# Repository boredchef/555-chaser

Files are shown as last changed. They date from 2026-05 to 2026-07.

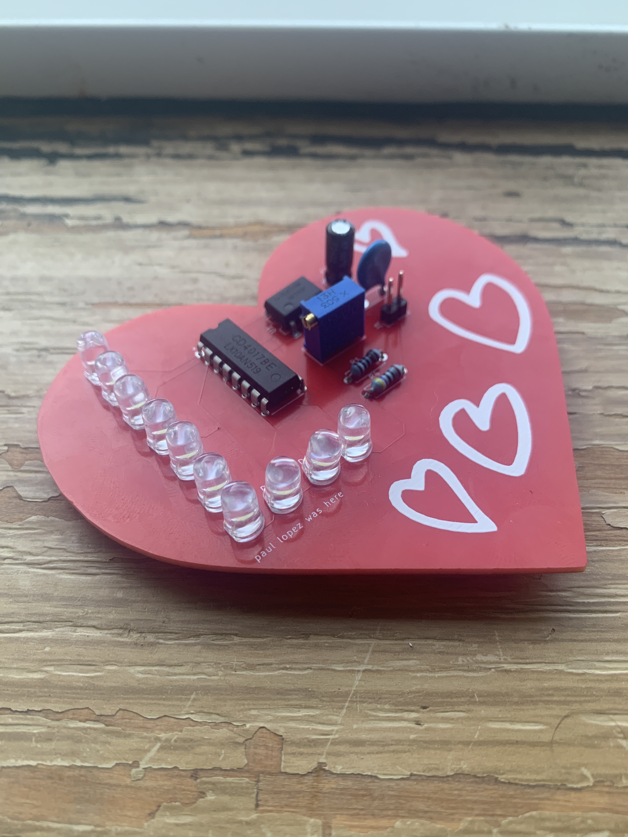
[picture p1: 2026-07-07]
IMG_1859.JPG

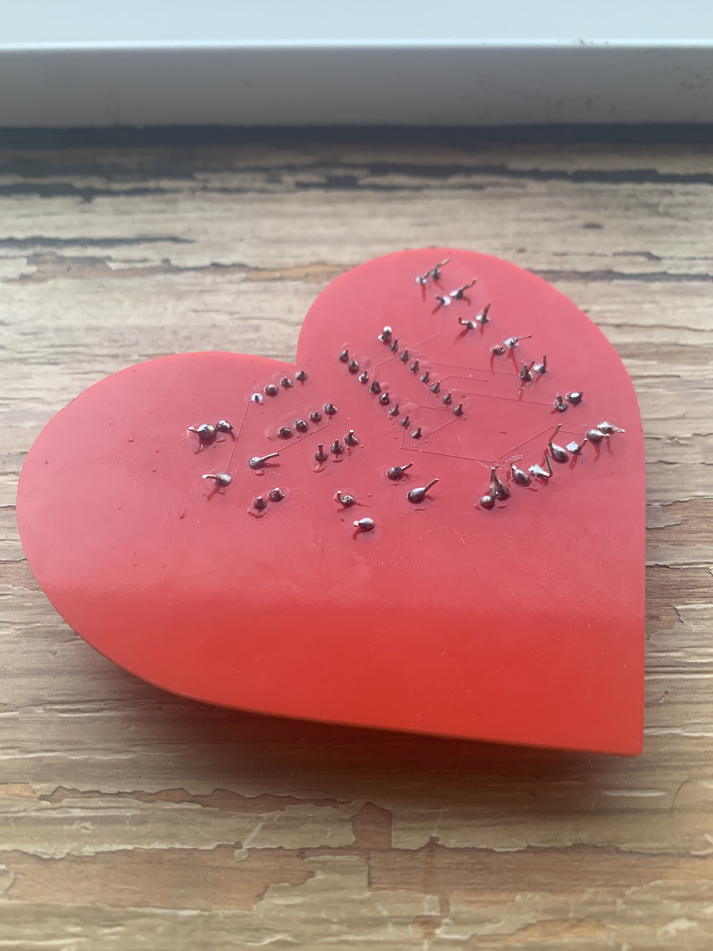
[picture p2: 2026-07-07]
IMG_1860.JPG

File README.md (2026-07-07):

# 555-chaser
I made this heart shaped led chaser PCB from the start project tutorial on Stasis. How it works is that it uses 2 different ICs which is the 555 timer and the 4017 IC. The 555 component basically is the brains to make the leds blink on and off using astable mode which produces an signal that swithces from on and off. Since we are using a lot of LEDs there is not enough pins on the 555 timer to wire them all so that is why we use the 4017 IC which has the pins. 

This PCB when connected to power and when the potentiometer is turned to let power through the components which then tell the leds to turn on and off. I used this starter project since I thought it would be really fun to learn how to design pcbs using software instead of having to wire things individually on a breadboard and be able to see something from CAD software come to life in hardware which is pretty sick, I also added hearts to gift to someone special :) 


above is the 3D view of the PCB but it does not render the potentiometer or the 4017 IC 


Finished PCB Front

Finished PCB Back

## BoM

| Name | Purpose | Qty | Total | Link | Distributor | 
| --- | --- | --- | --- | --- | --- |
| blinky board kit | leds, ICs, resistors, potentiometer | 1 | $10 | - | HackClub
| custom pcb | the actual design itself with copper plates | 5 | $5.30 | https://jlcpcb.com/ | JLCPCB

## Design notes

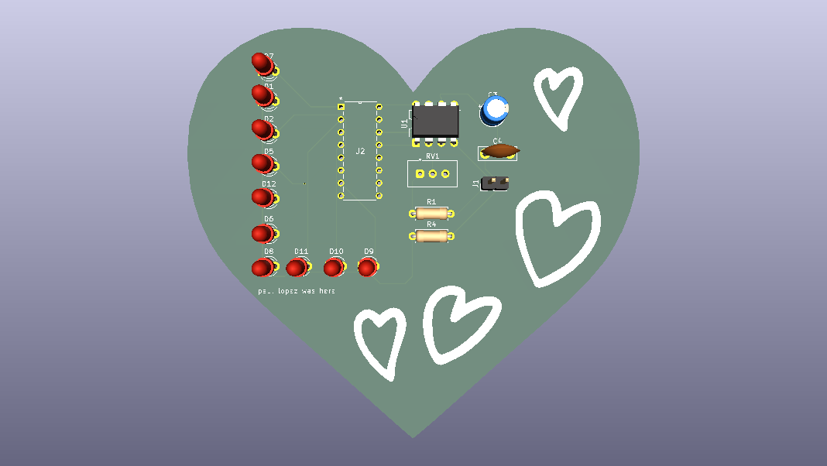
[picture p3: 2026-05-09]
555chaser.png

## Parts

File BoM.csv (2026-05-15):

Name | Purpose | Quantity | subtotal | tax | shipping | total cost | Link | Distributor
custom pcb | pcb for the blinkyboard with shape | 5 | 2.00 | n/a | 3.30 | 5.30 | https://jlcpcb.com/ | JLCPCB
kit | leds, resistors, timer IC, led IC, capacitors & potentiometer | 1 | 10 | N/A | N/A | 10 | https://stasis.hackclub.com/starter-projects/blinky | "HackClub"

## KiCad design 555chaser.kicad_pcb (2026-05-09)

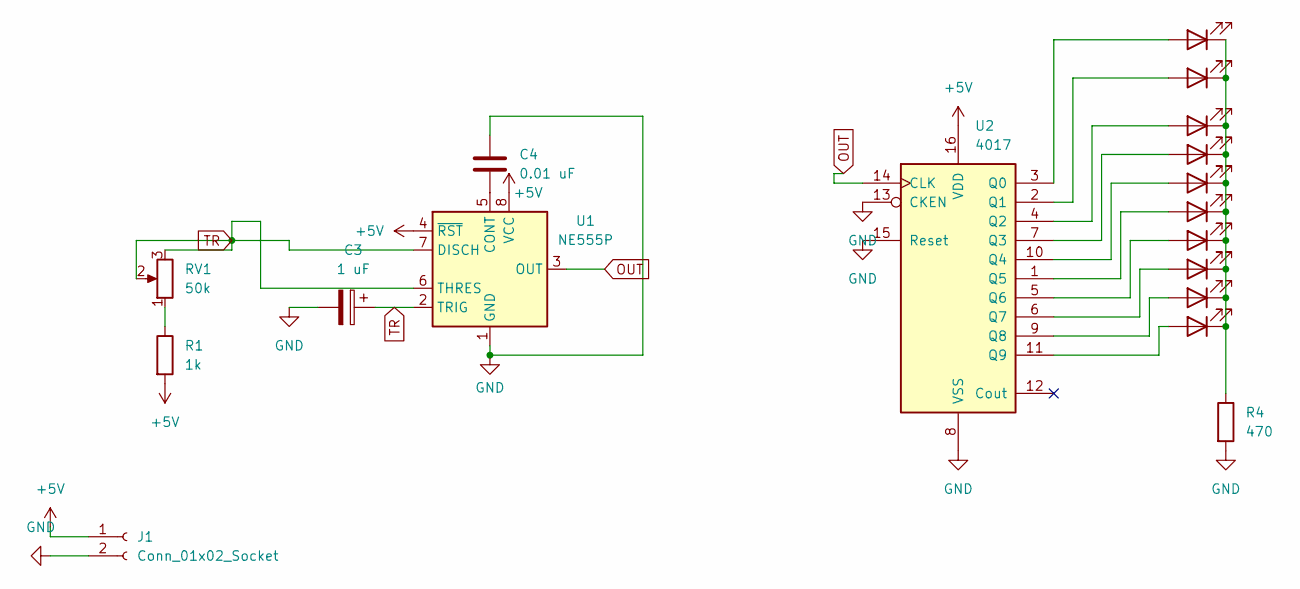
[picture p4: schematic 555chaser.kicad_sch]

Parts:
C3: 1 uF; CP_Radial_D5.0mm_P2.00mm
C4: 0.01 uF; C_Disc_D7.5mm_W2.5mm_P5.00mm
D1, D2, D5, D6, D7, D8, D9, D10, D11, D12: LED; LED_D3.0mm
J1: Conn_01x02_Socket; PinHeader_1x02_P2.54mm_Vertical
R1: 1k; R_Axial_DIN0207_L6.3mm_D2.5mm_P7.62mm_Horizontal
R4: 470; R_Axial_DIN0207_L6.3mm_D2.5mm_P7.62mm_Horizontal
RV1: 50k; Potentiometer_Vishay_T93YA_Vertical
U1: NE555P; DIP-8_W7.62mm
U2: 4017; N16

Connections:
+5V: J1.1, R1.2, U1.4 (~RST), U1.8 (VCC), U2.16 (VDD)
GND: C3.2, C4.1, J1.2, R4.2, U1.1 (GND), U2.8 (VSS), U2.13 (CKEN), U2.15 (Reset)
unnamed: D1.2 (A), U2.11 (Q9)
unnamed: D1.1 (K), D2.1 (K), D5.1 (K), D6.1 (K), D7.1 (K), D8.1 (K), D9.1 (K), D10.1 (K), D11.1 (K), D12.1 (K), R4.1
unnamed: D2.2 (A), U2.5 (Q6)
unnamed: D5.2 (A), U2.9 (Q8)
unnamed: D6.2 (A), U2.6 (Q7)
unnamed: D7.2 (A), U2.1 (Q5)
unnamed: D8.2 (A), U2.10 (Q4)
unnamed: D9.2 (A), U2.7 (Q3)
unnamed: D10.2 (A), U2.4 (Q2)
unnamed: D11.2 (A), U2.2 (Q1)
unnamed: D12.2 (A), U2.3 (Q0)
unnamed: R1.1, RV1.1
unnamed: C4.2, U1.5 (CONT)
OUT: U1.3 (OUT), U2.14 (CLK)
TR: C3.1, RV1.2, RV1.3, U1.2 (TRIG), U1.6 (THRES), U1.7 (DISCH)

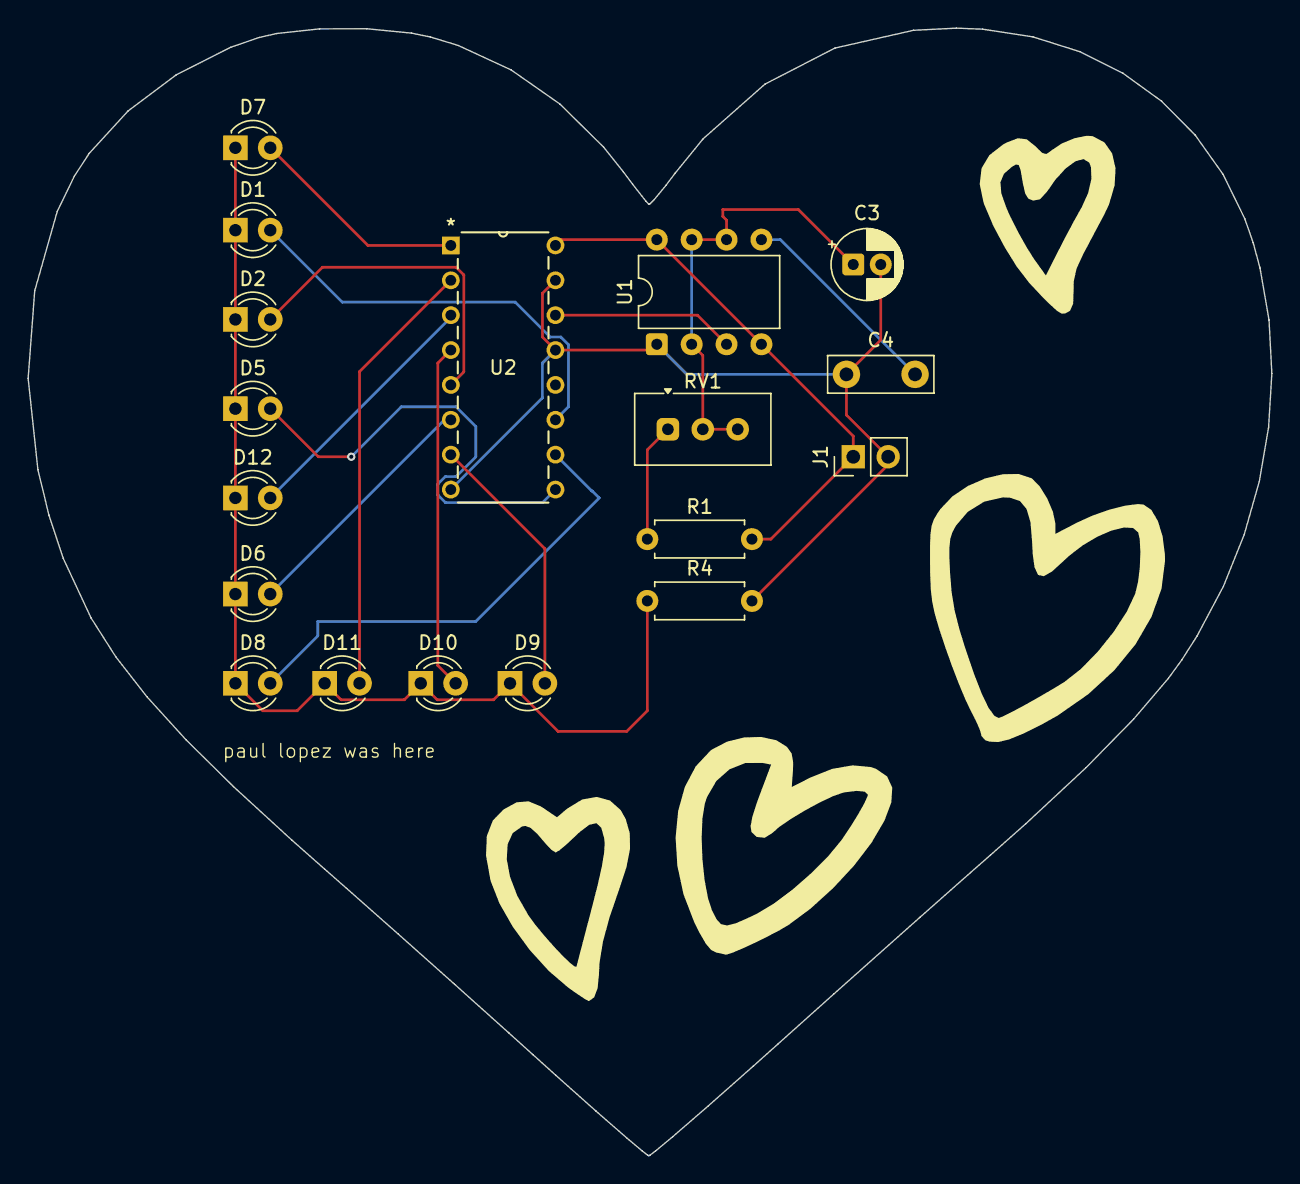
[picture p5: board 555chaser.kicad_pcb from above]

Board: 2 copper layers, 90.6 x 82.1 mm, 18 parts (0 on the bottom side), 17 nets.

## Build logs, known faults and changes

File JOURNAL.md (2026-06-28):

<!--
  This journal is auto generated by Stasis.
-->

# 5/9/2026 5 AM - adding lil art

_Time spent: 0.5833333333333334h_

# adding some art
today i spent the day trying to figure out how to add some kind of drawing to the pcb to try and figure out how to add some stuff to the empty space and so here was the process i found to be easy

first i went into a drawing app and used a screenshot of my pcb in order to know if i was drawing over any of the components and i decided to draw some silly hearts since i thought it fit what i was going for :)

so then i exported the image as a png and uploaded the graphic into the footprint editor into kicad which i figured out by looking at some forums after doin some research on google. i was able to save the footprint and then upload it onto the pcb's front silkscreen layer but i had to use the measurement tool in order to get the right size i wanted



after all that was done i was pretty content with how it looked and checked the design rules checker to make sure there wasn't any errors. the first time i drew an L over the LEDs and it gave me warnings about the silkscreen clearance interfering with the pads so i decided to get rid of it in order to not worry about it and just kept the hearts



this is the final thing, i know its pretty lame but i think its a nice touch to the pcb and ill be sure to use this process for adding more silkscreen art to more pcbs in the future




# 5/5/2026 3 AM - designing schematic & pcb

_Time spent: 4h_

## designing blinky board!! 

A couple of days ago I stumbled upon this starter project to design a pcb which I thought was pretty cool since I knew how to make circuits on a breadboard but had not gotten the chance to design a board that could be all wired together so I decided why not and take go at it. 

For the first hour I took a bit getting used to the kicad software since my computer was a bit slow and the software would sometimes stop responding on me but after a while I was able to copy down the symbols from the schematic and wire them together accordingly. I also had to look up a couple of the things such as the global labels and a video on how to upload the 4017 footprint library since I was a bit confused at how to do it. After putting together the schematic and assigning footprints I went on to do the pcb design.


above I highlighted the global labels I figured out how to put and pointed at places where I figured out how to change the labels of some symbols. I also found the shortcuts pretty easy like P for power and A for symbols.

The tricky part about the pcb design was really figuring out the most efficient way to lay out the components/footprints since I didn't want too many of the lines to intersect with each other and make it easier for me when I actually began to route and draw the connections.


I will *admit* I could have probably done a better job at arranging the components still but I think what made it easy was using both sides of the board to jump from the front copper layer and then the bottom copper layer to finish the connections. The blue lines are where back layer copper is and the red is front copper layer and it passed the design rules check so fingers crossed it actually works!

555chaser
Here is the finished 3d view, I decided to make it a heart and I just searched up an image and converted it to a dxf file which I found pretty interesting because its a new file format I had never seen before, I had sort of expected it to be svg file but theres that I suppose learn something new.

## reflection

overall I thought this was a pretty cool first project to start off with because I learned a lot about how to use a new software and actually designed a piece of hardware that can be hooked up to power and something I could gift to someone I know :)
